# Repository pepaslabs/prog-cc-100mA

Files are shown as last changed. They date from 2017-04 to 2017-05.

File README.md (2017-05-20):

# prog-cc-100mA
A programmable 100mA current source

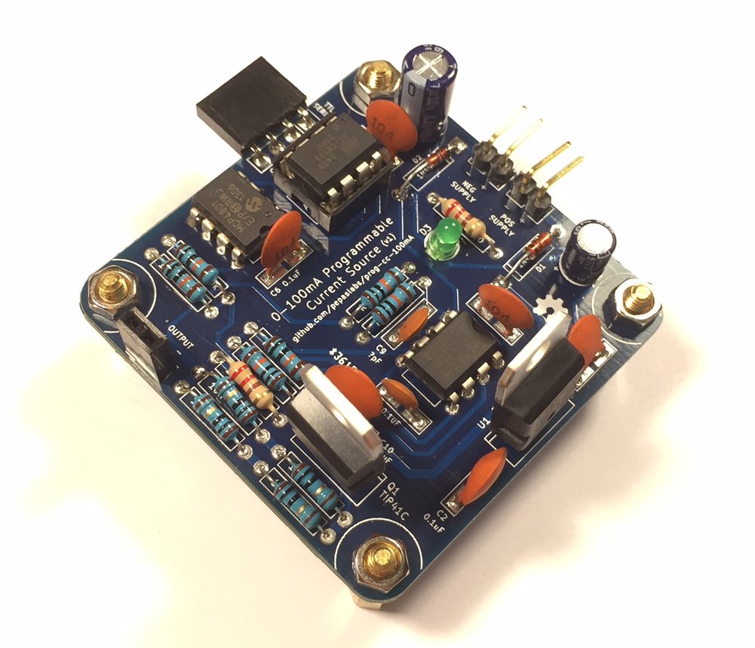
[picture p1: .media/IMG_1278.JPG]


# Status

This board has been tested and works.

With cheap components, it makes a decent low-precision current source.  I'm currently awaiting the arrival of some low temperature coefficient resistors and low input offset voltage opamps to see if performance can be improved.

# Board design v1

Initial board design.

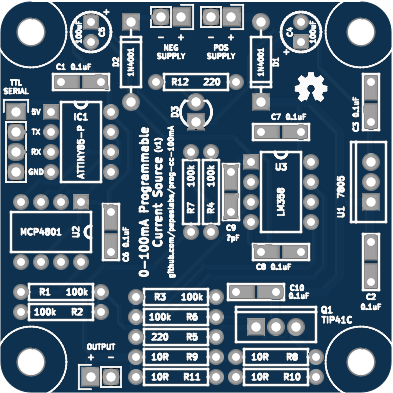
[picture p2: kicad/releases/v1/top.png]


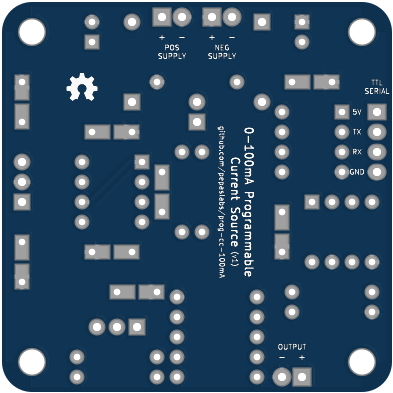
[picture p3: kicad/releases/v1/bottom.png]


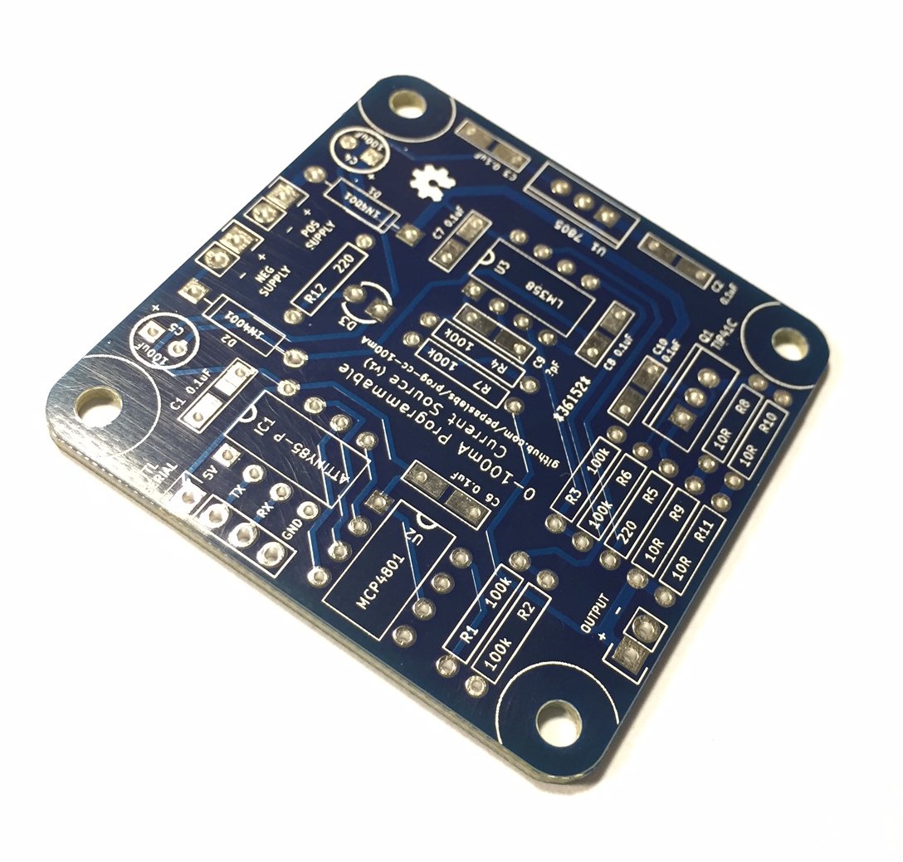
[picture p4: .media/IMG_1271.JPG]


## Gerbers

[gerbers.zip](kicad/releases/v1/gerbers.zip)

## Schematic

[PDF](kicad/releases/v1/prog-cc-100mA-schematic.pdf).

# License

This board design is [Open-Source Hardware](http://www.oshwa.org/definition/).  It is licensed under the [MIT License](http://opensource.org/licenses/MIT).  It was designed by Jason Pepas.

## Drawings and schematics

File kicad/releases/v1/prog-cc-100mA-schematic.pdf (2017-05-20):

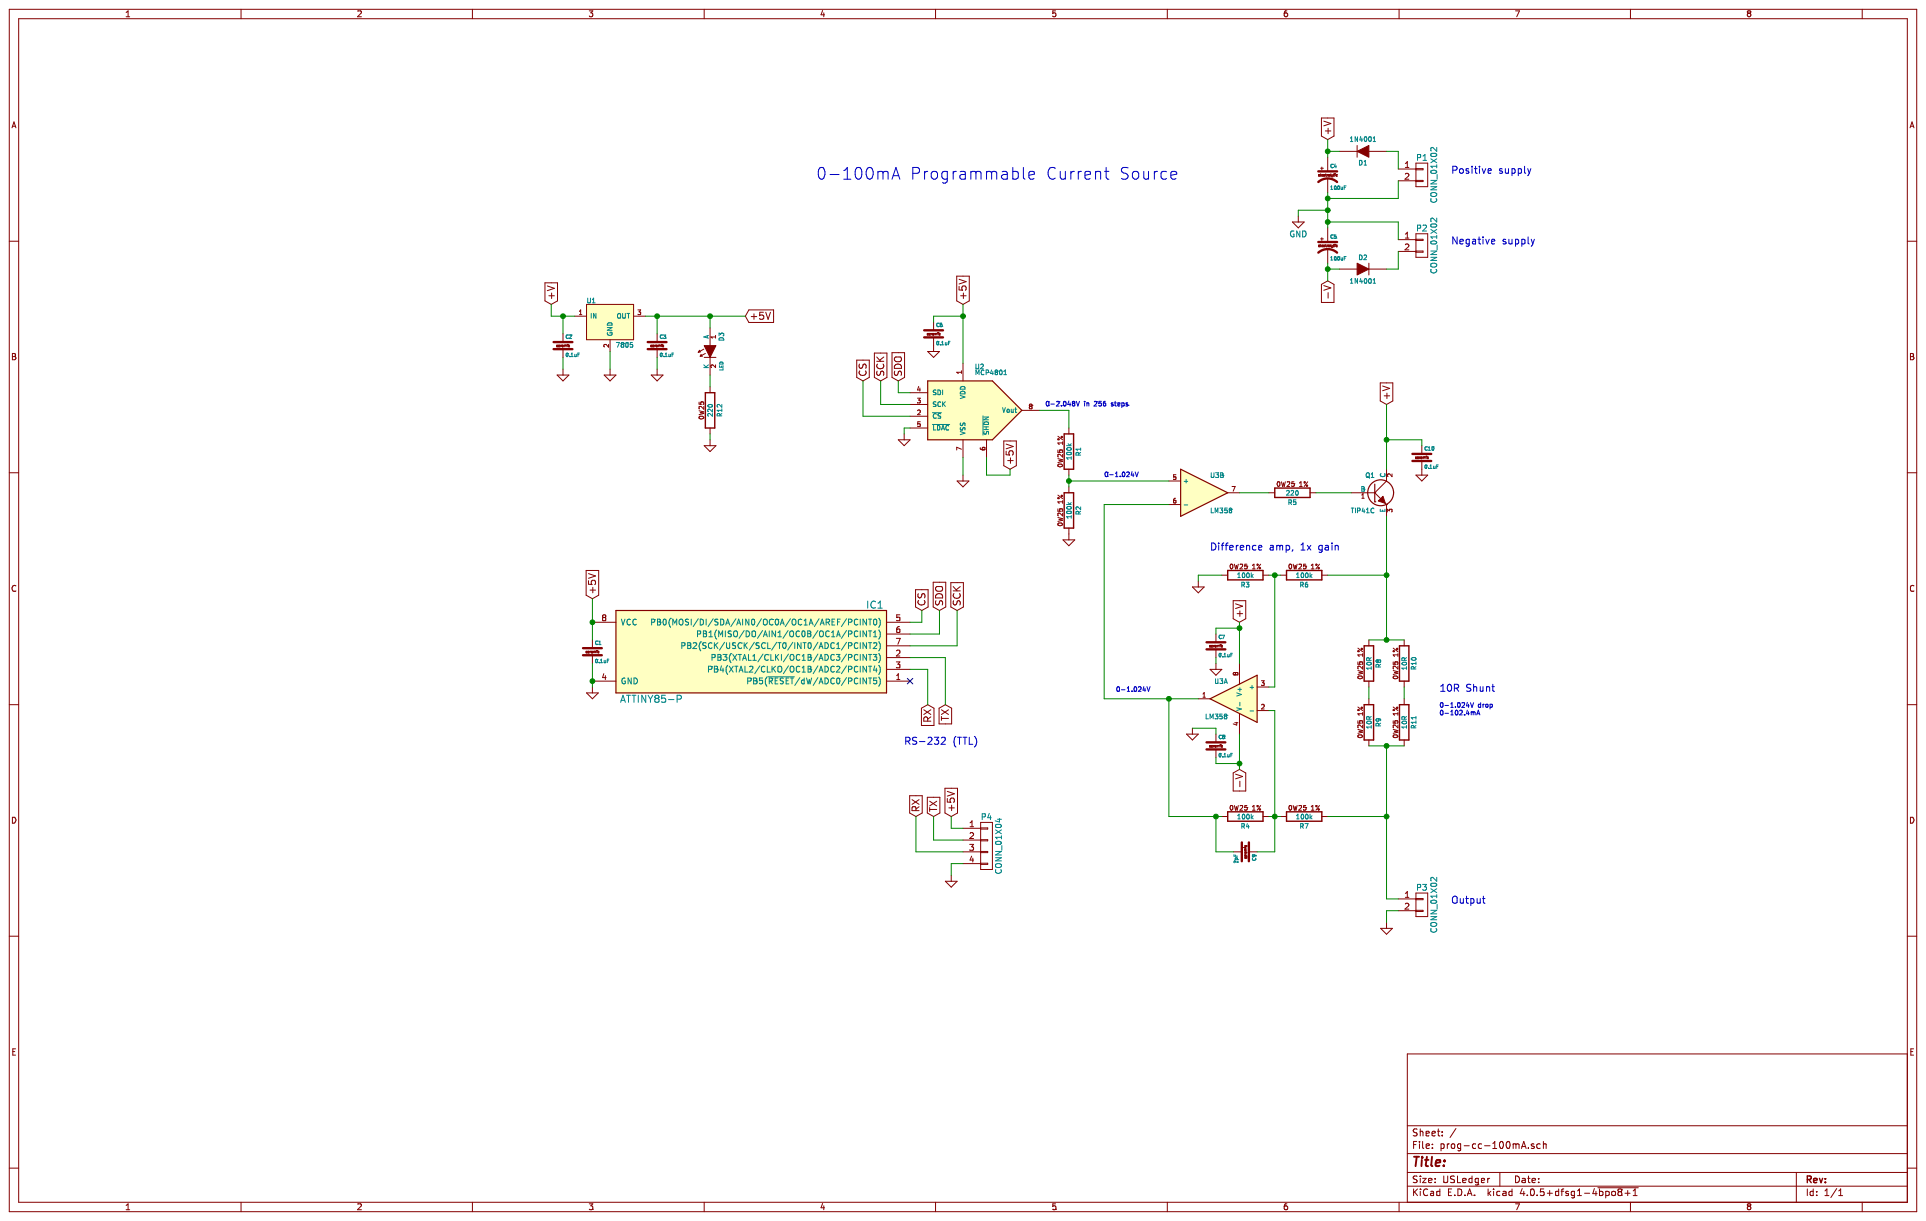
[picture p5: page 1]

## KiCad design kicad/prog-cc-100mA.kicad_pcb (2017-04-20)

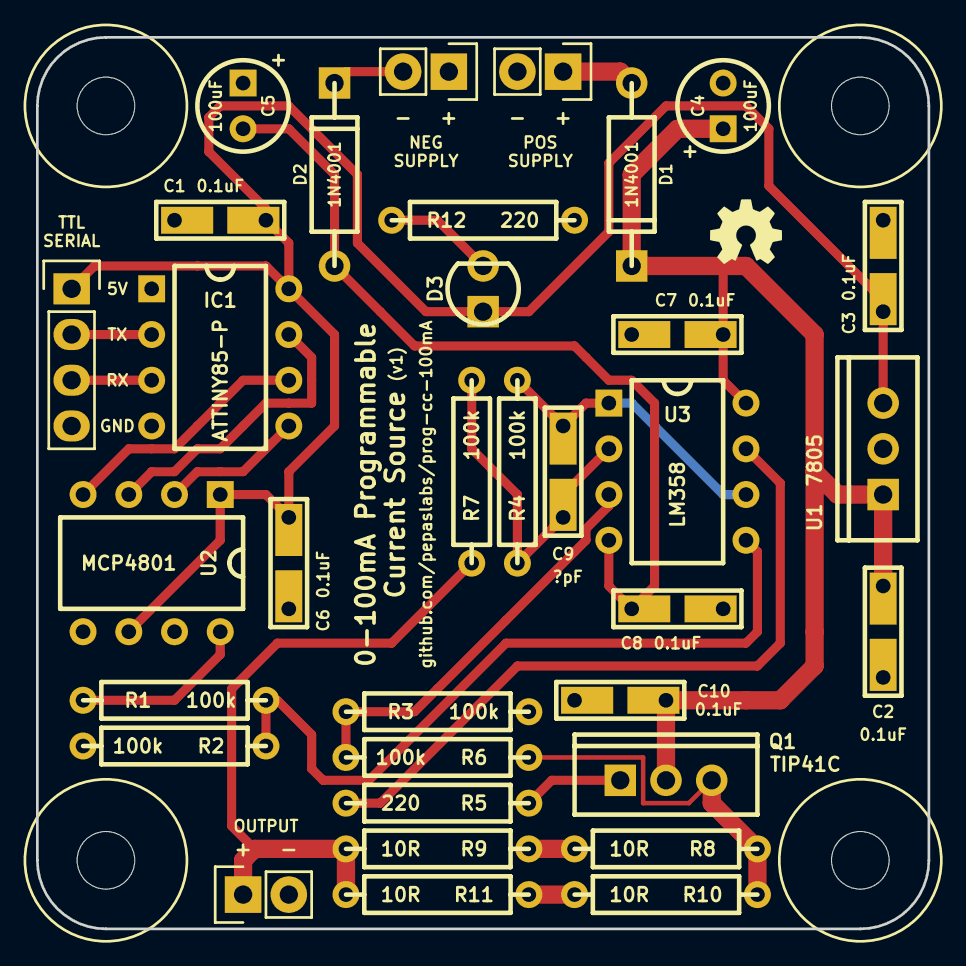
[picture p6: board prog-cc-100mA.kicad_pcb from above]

Board: 2 copper layers, 49.5 x 49.5 mm, 38 parts (0 on the bottom side), 23 nets.

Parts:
C1, C2, C3, C6, C7, C8, C10: 0.1uF; CERCAP_2_059B_0805
C4, C5: 100uF; ELCAP_10_20_V_059A
C9: ?pF; CERCAP_2_059B_0805
D1, D2: 1N4001; DIODE_1A_069A_PL
D3: LED; LED_3MM_069A
H***: Val**; hole_M3_NPTH
H***#2, H***#3, H***#4: Val**; hole_M3_NPTH
IC1: ATTINY85-P; DIP8_059A_PL
P1, P2, P3: CONN_01X02; Pin_Header_Straight_1x02
P4: CONN_01X04; Pin_Header_Straight_1x04
Q1: TIP41C; TO-220_V_069A
R1, R2, R3, R4, R6, R7: 100k; R_AXIAL_0W25_059A_PL
R5, R12: 220; R_AXIAL_0W25_059A_PL
R8, R9, R10, R11: 10R; R_AXIAL_0W25_059A_PL
U1: 7805; TO-220_V_069A
U2: MCP4801; DIP8_059A_PL
U3: LM358; DIP8_059A_PL

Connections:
+5V: C1.1, C3.1, C6.1, D3.1, IC1.8, P4.1, U1.3, U2.1, U2.6
+V: C2.1, C4.1, C7.1, C10.1, D1.2, Q1.2, U1.1, U3.8
-V: C5.2, C8.2, D2.1, U3.4
CS: IC1.5, U2.2
GND: C1.2, C2.2, C3.2, C4.2, C5.1, C6.2, C7.2, C8.1, C10.2, IC1.4, P1.2, P2.1, P3.2, P4.4, R2.2, R3.2, R12.2, U1.2, U2.5, U2.7
unnamed: C9.1, R4.1, R7.2, U3.2
unnamed: C9.2, R4.2, U3.1, U3.6
unnamed: D1.1, P1.1
unnamed: D2.2, P2.2
unnamed: D3.2, R12.1
unnamed: Q1.1, R5.1
unnamed: Q1.3, R6.1, R8.1, R10.1
unnamed: R1.1, U2.8
unnamed: R1.2, R2.1, U3.5
unnamed: R3.1, R6.2, U3.3
unnamed: R5.2, U3.7
unnamed: R8.2, R9.1
unnamed: R10.2, R11.1
Out: P3.1, R7.1, R9.2, R11.2
RX: IC1.3, P4.3
SCK: IC1.7, U2.3
SDO: IC1.6, U2.4
TX: IC1.2, P4.2

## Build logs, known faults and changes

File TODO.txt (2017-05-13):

- add a reset button
- add a power switch?
- increase font size of + and - symbols on power plugs
- add diode on the output?
- create a version with built-in optoisolators?  and built-in FTDI/USB?
- create a version which uses rotary encoders for manual control via DAC?
- characterize the step-change response
- characterize the tempco of the unit
- try a variant with better resistors
- try a variant with all 5% resistors?
- move away from semi-colon as deliminator.  use newlines.
- add room for a heatsink?
- add circuitry to achieve true zero output?  a transistor to pull down a line or a trim pot to adjust the zero.
- redesign this board to use a single (low offset) opamp (e.g. OPO7)

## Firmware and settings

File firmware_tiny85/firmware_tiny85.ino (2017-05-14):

/*
  firmware_tiny85.ino: Arduino sketch for the programmable 0-100mA current source project.
  See https://github.com/pepaslabs/prog-cc-100mA
  Copyright Jason Pepas (Pepas Labs, LLC)
  Released under the terms of the MIT License.  See http://opensource.org/licenses/MIT
*/

/*
 This sketch requires ATTinyCore.  See installation instructions at:
 https://github.com/SpenceKonde/ATTinyCore/blob/master/Installation.md
 */

/*
Serial command examples:

'i': Set the output current to 5 milliamps:

    i5; or i5.0;

'c': Set the DAC output code to 37, no gain:

    c37;
    
'C': Set the DAC output code to 217, with 2x gain:

    C217;

'+': Increase the DAC output by one LSB:

    +;

'-': Decrease the DAC output by one LSB:

    -;

(Note: '+' and '-' do not alter the DAC gain boolean.)

'z': Calibrate the zero output to 0.05mA:

    z0.05;

'f': Calibrate full-scale output to 101.3mA:

    f101.3;

'?': Dump the current state:

    ?;

'd': Disable verbose debug output (default):

    d;

'D': Enable verbose debug output:

    D;
*/

/*
A note about DAC selection and the 'C' command:

The 'c' and 'C' commands are relative to the resolution of the DAC.

To set an MCP4801 (8-bit) DAC to max output current:

    C255;

To set an MCP4811 (10-bit) DAC to max output current:

    C1023;

To set an MCP4821 (12-bit) DAC to max output current:

    C4095;
*/    

// Hex file compiled using Arduino 1.8.2 for ATtiny85 consumes:
// ->  7,034 (of 8,192) bytes of flash
// ->  284 (of 512) bytes of SRAM for global variables

// Pull in uint8_t, uint16_t, etc.
#define __STDC_LIMIT_MACROS
#include <stdint.h>

// Pull in EEMEM, etc.
// see http://www.atmel.com/webdoc/avrlibcreferencemanual/group__avr__eeprom.html
#include <avr/eeprom.h>

#include "features.h"

#include <SoftwareSerial.h>

#include "buffer.h"
#include "pins.h"
#include "SPI_util.h"
#include "DAC_util.h"
#include "MCP4821.h"

#include "command.h"


// --- Pinouts / connections:


// ATtiny85 pinout:
//
//                            +--\/--+
//                       D5  -|1    8|-  Vcc   (to 5V)
//      TTL serial TX    D3  -|2    7|-  D2    SPI SCK (to DAC SCK, pin 3)
//      TTL serial RX    D4  -|3    6|-  D1    SPI SDO (to DAC SDI, pin 4)
//                      GND  -|4    5|-  D0    SPI CS (to DAC CS, pin 2)
//                            +------+

// MCP4801 pinout:
//
//                            +--\/--+
//             (to 5V)  Vcc  -|1    8|-  Vout
//   (to tiny85 pin 5)  ~CS  -|2    7|-  GND
//   (to tiny85 pin 7)  SCK  -|3    6|-  ~SHDN  (to 5V)
//   (to tiny85 pin 6)  SDI  -|4    5|-  ~LDAC  (to GND)
//                            +------+


// --- DAC / SPI:


// Uncomment one of the following to choose your DAC:
//DAC_config_t dac_config = MCP4801_config(); // 8-bit, 0.4mA output resolution
//DAC_config_t dac_config = MCP4811_config(); // 10-bit, 0.1mA output resolution
DAC_config_t dac_config = MCP4821_config(); // 12-bit, 0.025mA output resolution


DAC_data_t dac_data = { .config = &dac_config, .gain = false, .code = 0x0 };


SPI_bus_t spi_bus = { .MOSI_pin = ATTINY85_PIN_6,
                      .MISO_pin = PIN_NOT_CONNECTED,
                      .SCK_pin = ATTINY85_PIN_7,
                      .type = BITBANG
                    };


SPI_device_t spi_dac = { .bus = &spi_bus,
                         .CS_pin = ATTINY85_PIN_5,
                         .bit_order = MSBFIRST
                       };


// --- Serial interface:


#define RX_pin ATTINY85_PIN_3
#define TX_pin ATTINY85_PIN_2

SoftwareSerial serial(RX_pin, TX_pin);

#ifdef HAS_RUNTIME_VERBOSITY_CONFIG
bool verbose = false;
#endif


// --- buffer


#define MIN_EXPECTED_BUFF_LEN 2 // "+;"
#define MAX_EXPECTED_BUFF_LEN 9 // "i102.400;"
#define BUFF_LEN (MAX_EXPECTED_BUFF_LEN + 1)

char buffer_bytes[BUFF_LEN];
char_buffer_t buffer = { .len = BUFF_LEN, .bytes = buffer_bytes };


// --- Calibration values


// These can be calibrated over the serial connection, and are remembered via EEPROM.

// This is the measured output current (in milliamps) when the DAC is at min output (code 0).
float zero = 0.0;

// This is the measured output current (in milliamps) when the DAC is at max output (e.g., code 255 for an 8-bit DAC).
float full_scale = 102.4;


// A correction factor to apply to any requested current setting, based on the calibration settings.
struct _correction_t
{
  float offset;
  float scale;
};
typedef _correction_t correction_t;

//correction_t correction = { .offset = -(zero), .scale = 102.4 / (full_scale - zero) };
correction_t correction;


// --- Strings:


const char *STRING_BOOT_MESSAGE = "prog-cc-100mA OK;";
const char *STRING_PARSED_CURRENT = "current: ";
const char *STRING_CORRECTED_CURRENT = "corrected: ";
const char *STRING_DAC_CODE = "code: ";
const char *STRING_ZERO = "zero: ";
const char *STRING_FULL_SCALE = "full scale: ";
const char *STRING_DAC_RESOLUTION = "resolution: ";
const char *STRING_DAC_GAIN = "gain: ";
const char *STRING_CORRECTION_OFFSET = "offset: ";
const char *STRING_CORRECTION_SCALE = "scale: ";
const char *STRING_OK = "OK";
const char *STRING_ERROR = "!E";


// --- Setup & loop:


void setup()
{
  serial.begin(9600); // 9600 8N1

  #ifdef HAS_BOOT_MESSAGE
  {
    delay(10);
    serial.println(STRING_BOOT_MESSAGE);
    serial.flush();
  }
  #endif
  
  #ifdef HAS_EEPROM_BACKED_CALIBRATION_VALUES
  {
    bootstrap_EEPROM();
  }
  #endif

  // calculate the correction factor
  recalculate_correction_factor(zero, full_scale, &correction);
  
  // setup soft SPI
  pinMode(spi_bus.MOSI_pin, OUTPUT);
  pinMode(spi_bus.SCK_pin, OUTPUT);
  pinMode(spi_dac.CS_pin, OUTPUT);
  
  digitalWrite(spi_dac.CS_pin, HIGH); // start with the DAC un-selected.

  clear_char_buffer(&buffer);
}


void loop()
{
  read_and_run_command();
}


// --- EEPROM


#ifdef HAS_EEPROM_BACKED_CALIBRATION_VALUES

uint8_t EEMEM eeprom_has_been_initialized_token_address;
#define EEPROM_HAS_BEEN_INITIALIZED_CODE 44

float EEMEM zero_EEPROM_address;
float EEMEM full_scale_EEPROM_address;

bool eeprom_has_been_initialized()
{
  uint8_t has_been_initialized_token = eeprom_read_byte(&eeprom_has_been_initialized_token_address);
  return (has_been_initialized_token == EEPROM_HAS_BEEN_INITIALIZED_CODE);
}


void initialize_eeprom()
{
  eeprom_write_byte(&eeprom_has_been_initialized_token_address, EEPROM_HAS_BEEN_INITIALIZED_CODE);
  eeprom_write_float(&zero_EEPROM_address, zero);
  eeprom_write_float(&full_scale_EEPROM_address, full_scale);  
}


void load_values_from_eeprom()
{
  zero = eeprom_read_float(&zero_EEPROM_address);
  full_scale = eeprom_read_float(&full_scale_EEPROM_address);

  // also update the correction factor
  recalculate_correction_factor(zero, full_scale, &correction);
}

void bootstrap_EEPROM()
{
  if (eeprom_has_been_initialized() == false)
  {
    initialize_eeprom();
  }
  else
  {
    load_values_from_eeprom();
  }
}

#endif // HAS_EEPROM_BACKED_CALIBRATION_VALUES


// --- Calibration / correction factor:


void recalculate_correction_factor(float zero, float full_scale, correction_t *correction) {
  correction->offset = -(zero);
  correction->scale = 102.4 / (full_scale - zero);
}


// --- Serial utility functions:


void read_and_run_command()
{
  command_t command = read_command(&serial, &buffer);
  if (command >= END_OF_COMMANDS_SECTION)
  {
    #ifdef HAS_ERROR_PRINTING
    {
      printError(command);
    }
    #endif
    
    return;
  }

  error_t error;
  
  switch(command)
  {
    
    #ifdef HAS_INCREMENT_COMMAND
    case COMMAND_INCREMENT:
    {
      error = increment_output_current(&dac_data, &spi_dac);
      break;
    }
    #endif
  
    #ifdef HAS_DECREMENT_COMMAND
    case COMMAND_DECREMENT:
    {
      error = decrement_output_current(&dac_data, &spi_dac);
      break;
    }
    #endif
  
    #ifdef HAS_CURRENT_COMMAND
    case COMMAND_SET_CURRENT:
    {
      error = parse_and_run_current_command(&buffer, &dac_data, &spi_dac);
      break;
    }
    #endif
  
    #ifdef HAS_CODE_COMMAND
    case COMMAND_SET_CODE:
    {
      error = parse_and_run_code_command(&buffer, &dac_data, &spi_dac, false);
      break;
    }
    case COMMAND_SET_CODE_W_GAIN:
    {
      error = parse_and_run_code_command(&buffer, &dac_data, &spi_dac, true);
      break;
    }
    #endif

    #ifdef HAS_CALIBRATE_ZERO_COMMAND
    case COMMAND_CALIBRATE_ZERO:
    {
      error = parse_and_run_calibrate_zero_command(&buffer);
      break;
    }
    #endif
  
    #ifdef HAS_CALIBRATE_FULL_SCALE_COMMAND
    case COMMAND_CALIBRATE_FULL_SCALE:
    {
      error = parse_and_run_calibrate_full_scale_command(&buffer);
      break;
    }
    #endif
  
    #ifdef HAS_DUMP_COMMAND
    case COMMAND_DUMP:
    {
      error = dump(&dac_data);
      break;
    }
    #endif

    #ifdef HAS_RUNTIME_VERBOSITY_CONFIG
    case COMMAND_DISABLE_VERBOSE_DEBUG_OUTPUT:
    {
      verbose = false;
      error = OK_NO_ERROR;
      break;
    }
    case COMMAND_ENABLE_VERBOSE_DEBUG_OUTPUT:
    {
      verbose = true;
      error = OK_NO_ERROR;
      break;
    }
    #endif
    
    default:
    {
      error = ERROR_UNKNOWN_COMMAND;
      break;
    }
  }
  
  if (error != OK_NO_ERROR)
  {
    #ifdef HAS_ERROR_PRINTING
    {
      printError(error);
    }
    #endif
    
    return;
  }
  
  #ifdef HAS_SUCCESS_PRINTING
  {
    printSuccess(command);
  }
  #endif
}


command_t read_command(SoftwareSerial *serial, char_buffer_t *buffer)
{
  // strategy:
  // throw away any leading \r and \n
  // read the first char to determine which command this is
  // read the rest of the line into a buffer

  char command_ch;

  // read the first character to figure out which command this is
  while(true)
  {
    // busy-wait for serial data to become available
    while(serial->available() == 0)
    {
      continue;
    }

    command_ch = serial->read();

    // if this was leftover trailing newline garbage from the previous command, skip it
    if (command_ch == '\r' || command_ch == '\n')
    {
      continue;
    }
    else
    {
      break;
    }
  }

  uint8_t num_chars_consumed = 0;
  char *buff_ptr = buffer->bytes;

  // read the rest of the line into a buffer, which will be used by the command implementation
  while(true)
  {
    // busy-wait for serial data to become available
    while(serial->available() == 0)
    {
      continue;
    }
    
    *buff_ptr = serial->read();
    num_chars_consumed++;

    if (*buff_ptr == '\r' || *buff_ptr == '\n')
    {
      *buff_ptr = '\0';
      break;
    }
    else if (num_chars_consumed == buffer->len - 1)
    {
      *buff_ptr = '\0';
      return ERROR_BUFFER_FILLED_UP_BEFORE_SENTINEL_REACHED;
    }
    else
    {
      buff_ptr++;
      continue;
    }
  }
  
  switch(command_ch)
  {
    #ifdef HAS_INCREMENT_COMMAND
    case '+':
    {
      return COMMAND_INCREMENT;
    }
    #endif
    
    #ifdef HAS_DECREMENT_COMMAND
    case '-':
    {
      return COMMAND_DECREMENT;
    }
    #endif
    
    #ifdef HAS_CURRENT_COMMAND
    case 'i':
    {
      return COMMAND_SET_CURRENT;
    }
    #endif
    
    #ifdef HAS_CODE_COMMAND
    case 'c':
    {
      return COMMAND_SET_CODE;
    }
    case 'C':
    {
      return COMMAND_SET_CODE_W_GAIN;
    }
    #endif
    
    #ifdef HAS_CALIBRATE_ZERO_COMMAND
    case 'z':
    {
      return COMMAND_CALIBRATE_ZERO;
    }
    #endif
    
    #ifdef HAS_CALIBRATE_FULL_SCALE_COMMAND
    case 'f':
    {
      return COMMAND_CALIBRATE_FULL_SCALE;
    }
    #endif
    
    #ifdef HAS_DUMP_COMMAND
    case '?':
    {
      return COMMAND_DUMP;
    }
    #endif

    #ifdef HAS_RUNTIME_VERBOSITY_CONFIG
    case 'd':
    {
      return COMMAND_DISABLE_VERBOSE_DEBUG_OUTPUT;
    }
    case 'D':
    {
      return COMMAND_ENABLE_VERBOSE_DEBUG_OUTPUT;
    }
    #endif

    default:
    {
      return ERROR_UNKNOWN_COMMAND;
    }
  }
}


// --- DAC functions:


void send_dac_data(DAC_data_t *dac_data, SPI_device_t *spi_dac)
{
  MCP4821_packet_t packet = dac_data_as_MCP4821_packet(dac_data);
  spi_write_MCP4821_packet(spi_dac, packet);
}


// --- Command implementations:


#ifdef HAS_INCREMENT_COMMAND
error_t increment_output_current(DAC_data_t *dac_data, SPI_device_t *spi_dac)
{
  if (dac_data_increment_code(dac_data) == false)
  {
    return ERROR_INCREMENT_WOULD_CAUSE_OVERFLOW;
  }

  send_dac_data(dac_data, spi_dac);
  return OK_NO_ERROR;
}
#endif


#ifdef HAS_DECREMENT_COMMAND
error_t decrement_output_current(DAC_data_t *dac_data, SPI_device_t *spi_dac)
{
  if (dac_data_decrement_code(dac_data) == false)
  {
    return ERROR_DECREMENT_WOULD_CAUSE_UNDERFLOW;
  }

  send_dac_data(dac_data, spi_dac);
  return OK_NO_ERROR;
}
#endif


#ifdef HAS_CURRENT_COMMAND
error_t parse_and_run_current_command(char_buffer_t *buffer, DAC_data_t *dac_data, SPI_device_t *spi_dac)
{
  float output_current = atof(buffer->bytes);

  #ifdef HAS_RUNTIME_VERBOSITY_CONFIG
  #ifdef HAS_CURRENT_COMMAND_DEBUGGING
  if (verbose == true)
  {
    serial.print(STRING_PARSED_CURRENT);
    serial.println(output_current, 4);
    serial.flush();
  }
  #endif
  #endif

  if (output_current < 0)
  {
    return ERROR_PARSED_CURRENT_OUTSIDE_SUPPORTED_RANGE;
  }

  // apply the correction factor to the requested output current
  output_current = (output_current + correction.offset) * correction.scale;
  if (output_current < 0) output_current = 0;
  if (output_current > 102.4) output_current = 102.4;

  #ifdef HAS_RUNTIME_VERBOSITY_CONFIG
  #ifdef HAS_CURRENT_COMMAND_DEBUGGING
  if (verbose == true)
  {
    serial.print(STRING_CORRECTED_CURRENT);
    serial.println(output_current, 4);
    serial.flush();
  }
  #endif
  #endif

  // We have a 10R shunt and a 2x divider
  // 102.4mA becomes a 1.024V drop across the shunt.  DAC needs to output 2.048V to achieve this.
  // 102.4 / 50 = 2.048
  float DAC_volts = output_current / 50.0;
    
  if (dac_data_set_voltage(dac_data, DAC_volts) == false)
  {
    return ERROR_PARSED_CURRENT_OUTSIDE_SUPPORTED_RANGE;
  }
  
  MCP4821_packet_t packet = dac_data_as_MCP4821_packet(dac_data);
  spi_write_MCP4821_packet(spi_dac, packet);
  
  return OK_NO_ERROR;
}
#endif


#ifdef HAS_CODE_COMMAND
error_t parse_and_run_code_command(char_buffer_t *buffer, DAC_data_t *dac_data, SPI_device_t *spi_dac, bool use_gain)
{
  uint16_t new_code = atoi(buffer->bytes);

  if (dac_data_set_code(dac_data, new_code) == false)
  {
    return ERROR_PARSED_CODE_OUTSIDE_SUPPORTED_RANGE;
  }
  
  dac_data->gain = use_gain;
  
  send_dac_data(dac_data, spi_dac);
  return OK_NO_ERROR;
}
#endif


#ifdef HAS_CALIBRATE_ZERO_COMMAND
error_t parse_and_run_calibrate_zero_command(char_buffer_t *buffer)
{
  float new_zero = atof(buffer->bytes);
  
  #ifdef HAS_RUNTIME_VERBOSITY_CONFIG  
  #ifdef HAS_CALIBRATE_ZERO_COMMAND_DEBUGGING
  if (verbose == true)
  {
    serial.print(STRING_ZERO);
    serial.println(new_zero, 4);
    serial.flush();
  }
  #endif
  #endif

  // check that the requested new zero value is sane
  if (new_zero < -1.0 || new_zero > 1.0)
  {
    return ERROR_PARSED_ZERO_OUTSIDE_SUPPORTED_RANGE;
  }

  zero = new_zero;
  
  #ifdef HAS_EEPROM_BACKED_CALIBRATION_VALUES
  {
    eeprom_write_float(&zero_EEPROM_address, zero);  
  }
  #endif

  // also update the correction factor
  recalculate_correction_factor(zero, full_scale, &correction);
  
  return OK_NO_ERROR;  
}
#endif


#ifdef HAS_CALIBRATE_FULL_SCALE_COMMAND
error_t parse_and_run_calibrate_full_scale_command(char_buffer_t *buffer)
{
  float new_full_scale = atof(buffer->bytes);
  
  #ifdef HAS_RUNTIME_VERBOSITY_CONFIG
  #ifdef HAS_CALIBRATE_FULL_SCALE_COMMAND_DEBUGGING
  if (verbose == true)
  {
    serial.print(STRING_FULL_SCALE);
    serial.println(new_full_scale, 4);
    serial.flush();
  }
  #endif
  #endif

  // check that the requested new full-scale value is sane
  if (new_full_scale < (102.4 * 0.9) || new_full_scale > (102.4 * 1.1))
  {
    return ERROR_PARSED_FULL_SCALE_OUTSIDE_SUPPORTED_RANGE;
  }
  
  full_scale = new_full_scale;
  
  #ifdef HAS_EEPROM_BACKED_CALIBRATION_VALUES
  {
    eeprom_write_float(&full_scale_EEPROM_address, full_scale);
  }
  #endif

  // also update the correction factor
  recalculate_correction_factor(zero, full_scale, &correction);

  return OK_NO_ERROR;  
}
#endif


#ifdef HAS_ERROR_PRINTING
void printError(error_t error)
{
  serial.print(STRING_ERROR);
  serial.println(error);
  serial.flush();
}
#endif


#ifdef HAS_SUCCESS_PRINTING
void printSuccess(command_t command)
{
  serial.print(STRING_OK);
  serial.print(command);
  serial.print(", ");
  serial.print(STRING_DAC_CODE);
  serial.println(dac_data.code);
  serial.flush();
}
#endif


#ifdef HAS_DUMP_COMMAND
error_t dump(DAC_data_t *dac_data)
{
  serial.print(STRING_DAC_RESOLUTION);
  serial.println(dac_config.resolution);
  serial.print(STRING_DAC_CODE);
  serial.println(dac_data->code);
  serial.print(STRING_DAC_GAIN);
  serial.println(dac_data->gain);
  serial.print(STRING_ZERO);
  serial.println(zero, 4);
  serial.print(STRING_FULL_SCALE);
  serial.println(full_scale, 4);
  serial.print(STRING_CORRECTION_OFFSET);
  serial.println(correction.offset, 4);
  serial.print(STRING_CORRECTION_SCALE);
  serial.println(correction.scale, 4);
  serial.flush();
  return OK_NO_ERROR;
}
#endif

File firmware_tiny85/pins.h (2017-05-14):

/*
  pins.h
  Copyright Jason Pepas (Pepas Labs, LLC)
  Released under the terms of the MIT License.  See http://opensource.org/licenses/MIT
*/

#ifndef _PINS_H_
#define _PINS_H_

#include <Arduino.h>


// Arduino logical pin numbering:

#define ARDUINO_PIN_D0 0
#define ARDUINO_PIN_D1 1
#define ARDUINO_PIN_D2 2
#define ARDUINO_PIN_D3 3
#define ARDUINO_PIN_D4 4
#define ARDUINO_PIN_D5 5
#define ARDUINO_PIN_D6 6
#define ARDUINO_PIN_D7 7
#define ARDUINO_PIN_D8 8
#define ARDUINO_PIN_D9 9
#define ARDUINO_PIN_D10 10
#define ARDUINO_PIN_D11 11
#define ARDUINO_PIN_D12 12
#define ARDUINO_PIN_D13 13

#define ARDUINO_PIN_A0 A0
#define ARDUINO_PIN_A1 A1
#define ARDUINO_PIN_A2 A2
#define ARDUINO_PIN_A3 A3
#define ARDUINO_PIN_A4 A4
#define ARDUINO_PIN_A5 A5


// ATmega328 (PDIP) pinout:
//
//                            +---\/---+
//     (PCINT14/!RESET) PC6  -|1     28|-  PC5 (ADC5/SCL/PCINT13)
//        (PCINT16/RXD) PD0  -|2     27|-  PC4 (ADC4/SDA/PCINT12)
//        (PCINT17/TXD) PD1  -|3     26|-  PC3 (ADC3/PCINT11)
//       (PCINT18/INT0) PD2  -|4     25|-  PC2 (ADC2/PCINT10)
//  (PCINT19/OC2B/INT1) PD3  -|5     24|-  PC1 (ADC1/PCINT9)
//     (PCINT20/XCK/T0) PD4  -|6     23|-  PC0 (ADC0/PCINT8)
//                      Vcc  -|7     22|-  GND
//                      GND  -|8     21|-  AVREF
// (PCINT6/XTAL1/TOCS1) PB6  -|9     20|-  AVCC
// (PCINT7/XTAL2/TOSC2) PB7  -|10    19|-  PB5 (SCK/PCINT5)
//    (PCINT21/OC0B/T1) PD5  -|11    18|-  PB4 (MISO/PCINT4)
//  (PCINT22/OC0A/AIN0) PD6  -|12    17|-  PB3 (MOSI/OC2A/PCINT3)
//       (PCINT23/AIN1) PD7  -|13    16|-  PB2 (!SS/OC1B/PCINT2)
//   (PCINT0/CLK0/ICP1) PB0  -|14    15|-  PB1 (OC1A/PCINT1)
//                            +--------+

// ATmega328 -> Arduino pin mapping:
//
//                            +---\/---+
//                           -|1     28|-  A5
//                       D0  -|2     27|-  A4
//                       D1  -|3     26|-  A3
//                       D2  -|4     25|-  A2
//                       D3  -|5     24|-  A1
//                       D4  -|6     23|-  A0
//                      Vcc  -|7     22|-  GND
//                      GND  -|8     21|-  
//                           -|9     20|-  
//                           -|10    19|-  D13
//                       D5  -|11    18|-  D12
//                       D6  -|12    17|-  D11
//                       D7  -|13    16|-  D10
//                       D8  -|14    15|-  D9
//                            +--------+

// (for PDIP package:)

#define  ATMEGA328_PIN_2   ARDUINO_PIN_D0
#define  ATMEGA328_PIN_3   ARDUINO_PIN_D1
#define  ATMEGA328_PIN_4   ARDUINO_PIN_D2
#define  ATMEGA328_PIN_5   ARDUINO_PIN_D3
#define  ATMEGA328_PIN_6   ARDUINO_PIN_D4
#define  ATMEGA328_PIN_11  ARDUINO_PIN_D5
#define  ATMEGA328_PIN_12  ARDUINO_PIN_D6
#define  ATMEGA328_PIN_13  ARDUINO_PIN_D7
#define  ATMEGA328_PIN_14  ARDUINO_PIN_D8
#define  ATMEGA328_PIN_15  ARDUINO_PIN_D9
#define  ATMEGA328_PIN_16  ARDUINO_PIN_D10
#define  ATMEGA328_PIN_17  ARDUINO_PIN_D11
#define  ATMEGA328_PIN_18  ARDUINO_PIN_D12
#define  ATMEGA328_PIN_19  ARDUINO_PIN_D13

#define  ATMEGA328_PIN_23  ARDUINO_PIN_A0
#define  ATMEGA328_PIN_24  ARDUINO_PIN_A1
#define  ATMEGA328_PIN_25  ARDUINO_PIN_A2
#define  ATMEGA328_PIN_26  ARDUINO_PIN_A3
#define  ATMEGA328_PIN_27  ARDUINO_PIN_A4
#define  ATMEGA328_PIN_28  ARDUINO_PIN_A5


// ATtiny85 (PDIP) pinout:
//
//                                      +--\/--+
//        (PCINT5/!RESET/ADC0/dW) PB5  -|1    8|-  Vcc
// (PCINT3/XTAL1/CLKI/!OC1B/ADC3) PB3  -|2    7|-  PB2 (SCK/USCK/SCL/ADC1/T0/INT0/PCINT2)
//  (PCINT4/XTAL2/CLKO/OC1B/ADC2) PB4  -|3    6|-  PB1 (MISO/DO/AIN1/OC0B/OC1A/PCINT1)
//                                GND  -|4    5|-  PB0 (MOSI/DI/SDA/AIN0/OC0A/!OC1A/AREF/PCINT0)
//                                      +------+

// ATtiny85 -> Arduino pin mapping:
//
//                                      +--\/--+
//                                 D5  -|1    8|-  Vcc
//                                 D3  -|2    7|-  D2
//                                 D4  -|3    6|-  D1
//                                GND  -|4    5|-  D0
//                                      +------+

// (for PDIP / SOIC / TSSOP package:)

#define  ATTINY85_PIN_1  ARDUINO_PIN_D5
#define  ATTINY85_PIN_2  ARDUINO_PIN_D3
#define  ATTINY85_PIN_3  ARDUINO_PIN_D4
#define  ATTINY85_PIN_5  ARDUINO_PIN_D0
#define  ATTINY85_PIN_6  ARDUINO_PIN_D1
#define  ATTINY85_PIN_7  ARDUINO_PIN_D2


#endif

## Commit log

2017-04-20 Initial release (v1 board design)
    [prog-cc-100mA-B.Cu.gbr, prog-cc-100mA-B.Mask.gbr, prog-cc-100mA-B.SilkS.gbr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]
2017-04-20 Adding schematic pdf
2017-04-20 Tweaking PCB text layout
    [prog-cc-100mA.kicad_pcb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]
2017-04-20 Adding PCB renders
2017-04-22 moving schematic
2017-05-10 Tweaking a few part designations
    [prog-cc-100mA.sch]
2017-05-11 Adding resistor matching scripts
2017-05-13 adding board shots
2017-05-14 print the DAC code after every command
2017-05-20 rotating schematic
